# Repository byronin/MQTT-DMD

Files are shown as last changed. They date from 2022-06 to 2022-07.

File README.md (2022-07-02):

# MQTT-DMD for ESP8266

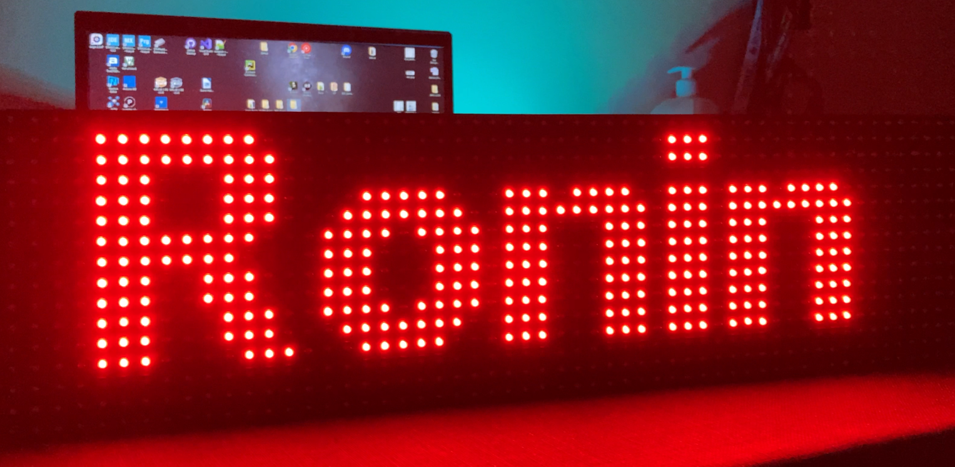
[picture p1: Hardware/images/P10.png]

## Contents
- PCB [Hardware](https://github.com/byronin/MQTT-DMD/tree/main/Hardware "Hardware") files prepared for controlling the P10 Display.
- [Arduino library](https://github.com/byronin/MQTT-DMD/tree/main/Lib%26Software "Arduino library")  for using P10 Display with Mqtt.

## Sponsor
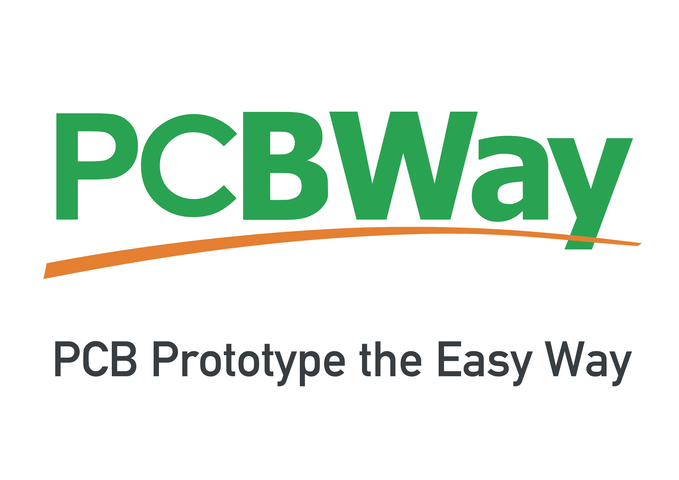
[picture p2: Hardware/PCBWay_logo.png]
(https://www.pcbway.com/project/shareproject/P10_Display_DMD_Text_Box_with_ESP8266_MQTT_P10_Display_Wi_Fi_Controller_4e9eb7f1.html)

#### Thanks to PCBWay for handling PCB production.
<a href="https://www.pcbway.com/project/shareproject/P10_Display_DMD_Text_Box_with_ESP8266_MQTT_P10_Display_Wi_Fi_Controller_4e9eb7f1.html">PCB from PCBWay</a>
## Hardware & BOM
PCBs
 This PCB Desing with Eagle PCB Desing with Eagle (https://www.autodesk.com/products/eagle/free-download "This PCB Desing with Eagle ") 
  ##### This PCB Desing with Eagle  
  
  ## Schematic
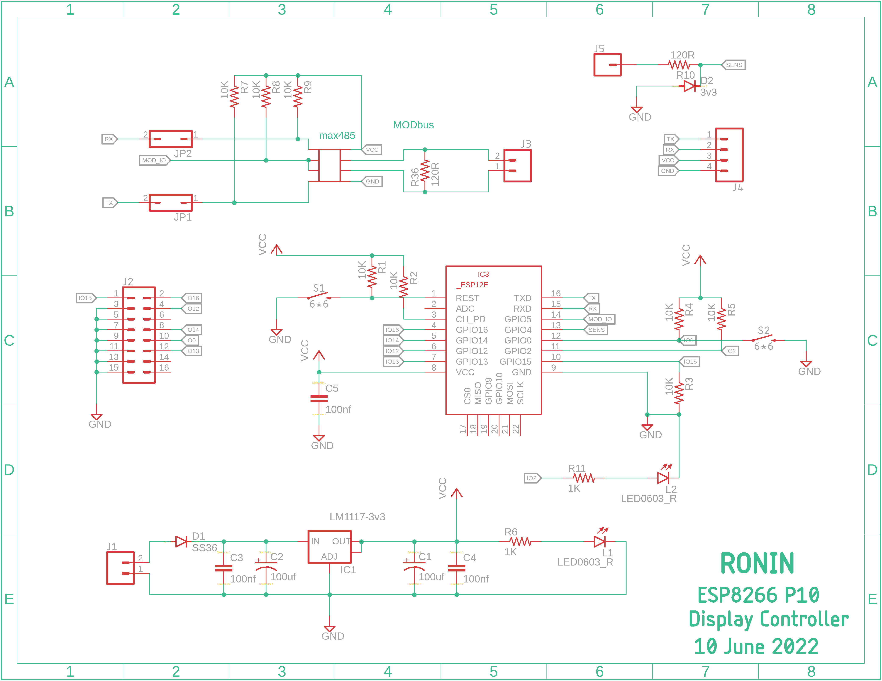
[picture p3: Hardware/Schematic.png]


| PCB Components  | Package |Piece || PCB Components  | Package |Piece |  
| --- | --- |--- |---| --- | --- |--- |
| ESP8266 Wi-Fi Module  | 12E | 1 pcs  || LM1117-3v3 | SOT-223  | 1 pcs |
| SS14/SS36 Diode  | DO-214AC | 1 pcs || 3v3 Zener Diode  | SOD80C | 1 pcs |
| MAX485-RS485 | SOP 8  | 1 pcs  || 100uf Cap | PANASONIC_D | 2 pcs |
| 100nf Cap mlcc | 0603  | 3 pcs || 10K Resistor  | 0603  | 8 pcs  |
| 1K Resistor | 0603  | 2 pcs || 120R Resistor  | 0603  | 2 pcs  |
| RED LED  | 0603  | 1 pcs || BLUE LED  | 0603  | 1 pcs  |
| Screw Terminal  | 3.5mm DIP  | 2 pcs  || Header 2x8 FML | 2.54-180  | 1 pcs  |
| Header 1x4 ML  | 2.54-90  | 1 pcs  || Header 1x2 ML  | 2.54-180  | 2 pcs  |
| JUMPER 1x2 | 2.54  | 2 pcs  |  

[You can look BOM.txt for details.](https://github.com/byronin/MQTT-DMD/blob/main/Hardware/BOM.txt "You can look BOM.txt")  

## Test 


#### Shopping List

| Product  | Link |
| --- | --- |
|P10 Display|[ Link](https://tr.aliexpress.com/item/1005003237909713.html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 " Link")|
| LM2596 |[Link](https://tr.aliexpress.com/item/33004374185.html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 "Link")|
| Power Jack |[Link](https://tr.aliexpress.com/item/32990462283.html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 "Link")  |
| 12V 3A Power Supply  | [Link](https://tr.aliexpress.com/item/32961533195.html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 "Link")  |

## Software & Library

- The project runs via the [Arduino IDE](https://www.arduino.cc/en/software "Arduino IDE"). If it is not installed, install it.
- Install [ESP8266](https://github.com/esp8266/Arduino "ESP8266") to Arduino.
- Install the [Pubsubclient Lib.](https://github.com/knolleary/pubsubclient "Pubsubclient Lib.") to Arduino.
- Install the [RoninDMD.zip](https://github.com/byronin/MQTT-DMD/blob/main/Lib%26Software/RoninDMD.zip "RoninDMD.zip") with library manager.
- You can connect with any MQTT client application. [MQTTool](https://apps.apple.com/us/app/mqttool/id1085976398 "MQTTool") application and [HiveMQ Public Broker](https://www.hivemq.com/public-mqtt-broker/ "HiveMQ Public Broker") were used in the testing phase of this project. Special thanks [@bjpetit](https://github.com/bjpetit "@bjpetit") .

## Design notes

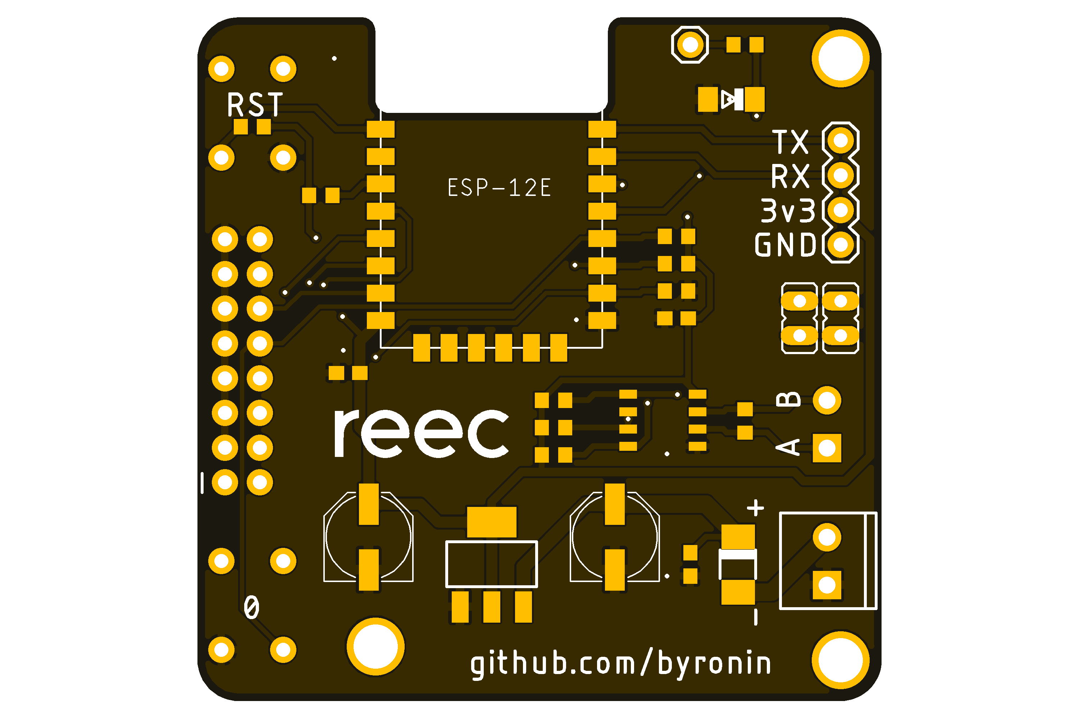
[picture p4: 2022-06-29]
Hardware/images/PCB1.png

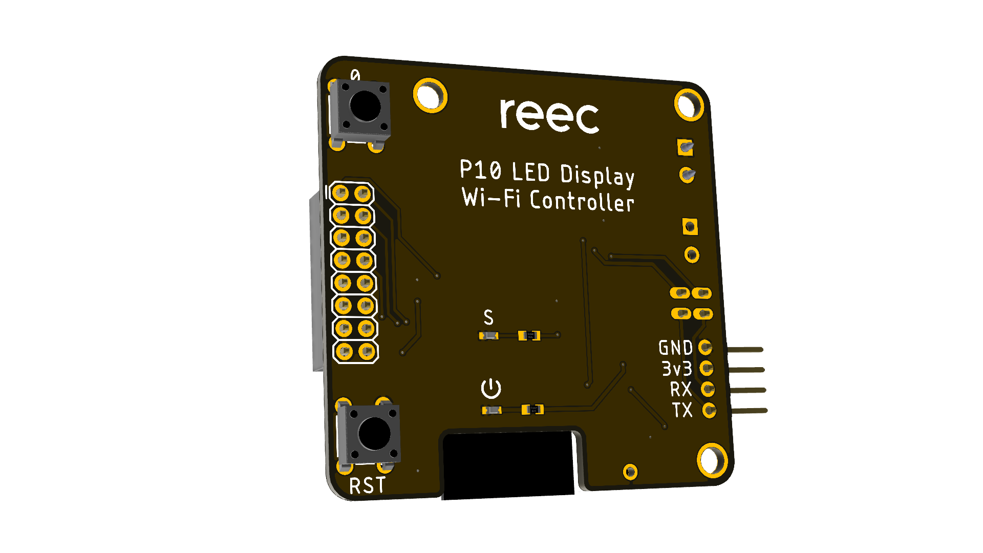
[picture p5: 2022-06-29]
Hardware/images/PCB_3D_2.png

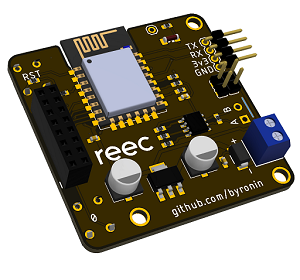
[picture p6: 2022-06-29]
Hardware/images/PCB_3D_1.png

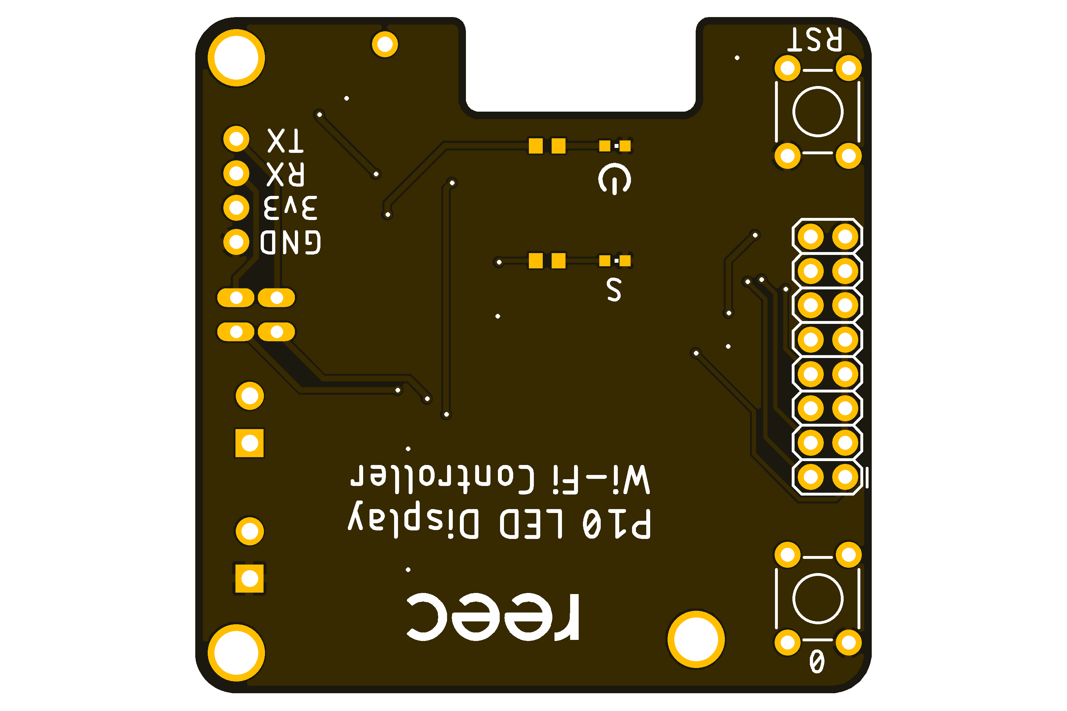
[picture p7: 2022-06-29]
Hardware/images/PCB2.png

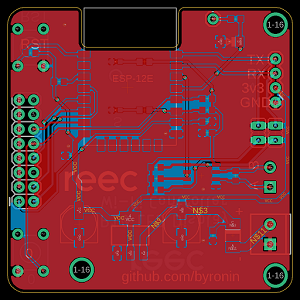
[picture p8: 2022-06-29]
Hardware/images/PCB_EAGLE.png

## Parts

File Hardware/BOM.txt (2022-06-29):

Partlist exported from C:/Users/Abdullah/Desktop/youtube/ESP8266_P10/Hardware/esp8266_p10/ESP8266_P10.sch at 12.06.2022 16:16

Part Value      Device                          Package                  Description                                                                                                      POPULARITY PROD_ID     SF_SKU   
C1   100uf      CAPACITOR_POLD                  PANASONIC_D                                                                                                                                                               
C2   100uf      CAPACITOR_POLD                  PANASONIC_D                                                                                                                                                               
C3   100nf      CAPACITOR_CER4                  C0603                                                                                                                                                                     
C4   100nf      CAPACITOR_CER4                  C0603                                                                                                                                                                     
C5   100nf      CAPACITOR_CER4                  C0603                                                                                                                                                                     
D1   SS36       DIODEAC2                        DO-214AC                                                                                                                                                                  
D2   3v3        DIODE80C                        SOD80C                                                                                                                                                                    
IC1  LM1117-3v3 V_REG_LM1117SOT223              SOT223                   Voltage Regulator LM1117                                                                                                                         
IC2  MAX485     SOP_8                           HSOP-8                                                                                                                                                                    
IC3             ESP8266-12EESP12E               ESP8266-ESP12E           ESP8266-12E Library for Eagle CAD                                                                                                                
J1              CONN_023.5MM                    SCREWTERMINAL-3.5MM-2    Multi connection point. Often used as Generic Header-pin footprint for 0.1 inch spaced/style header connections             CONN-08399           
J2              CONN_08X2                       2X8                      Multi connection point. Often used as Generic Header-pin footprint for 0.1 inch spaced/style header connections                                  
J3              CONN_023.5MM-NO_SILK            SCREWTERMINAL-3.5MM-2-NS Multi connection point. Often used as Generic Header-pin footprint for 0.1 inch spaced/style header connections             CONN-08399           
J4              CONN_04                         1X04                     Multi connection point. Often used as Generic Header-pin footprint for 0.1 inch spaced/style header connections             CONN-09696           
J5              CONN_01                         1X01                     Single connection point. Often used as Generic Header-pin footprint for 0.1 inch spaced/style header connections                                 
JP1             JP1Q                            JP1                      JUMPER                                                                                                           15                              
JP2             JP1Q                            JP1                      JUMPER                                                                                                           15                              
L1   LED0603_R  LED0603_R                       0603_LED_GREEN                                                                                                                                                            
L2   LED0603_R  LED0603_R                       0603_LED_GREEN                                                                                                                                                            
R1   10K        RESISTOR0603                    R0603                                                                                                                                                                     
R2   10K        RESISTOR0603                    R0603                                                                                                                                                                     
R3   10K        RESISTOR0603                    R0603                                                                                                                                                                     
R4   10K        RESISTOR0603                    R0603                                                                                                                                                                     
R5   10K        RESISTOR0603                    R0603                                                                                                                                                                     
R6   1K         RESISTOR0603                    R0603                                                                                                                                                                     
R7   10K        RESISTOR0603                    R0603                                                                                                                                                                     
R8   10K        RESISTOR0603                    R0603                                                                                                                                                                     
R9   10K        RESISTOR0603                    R0603                                                                                                                                                                     
R10  120R       RESISTOR0603                    R0603                                                                                                                                                                     
R11  1K         RESISTOR0603                    R0603                                                                                                                                                                     
R36  120R       RESISTOR0603                    R0603                                                                                                                                                                     
S1   6*6        MOMENTARY-SWITCH-SPST-PTH-6.0MM TACTILE_SWITCH_PTH_6.0MM Momentary Switch (Pushbutton) - SPST                                                                                         SWCH-08441 COM-00097
S2   6*6        MOMENTARY-SWITCH-SPST-PTH-6.0MM TACTILE_SWITCH_PTH_6.0MM Momentary Switch (Pushbutton) - SPST                                                                                         SWCH-08441 COM-00097

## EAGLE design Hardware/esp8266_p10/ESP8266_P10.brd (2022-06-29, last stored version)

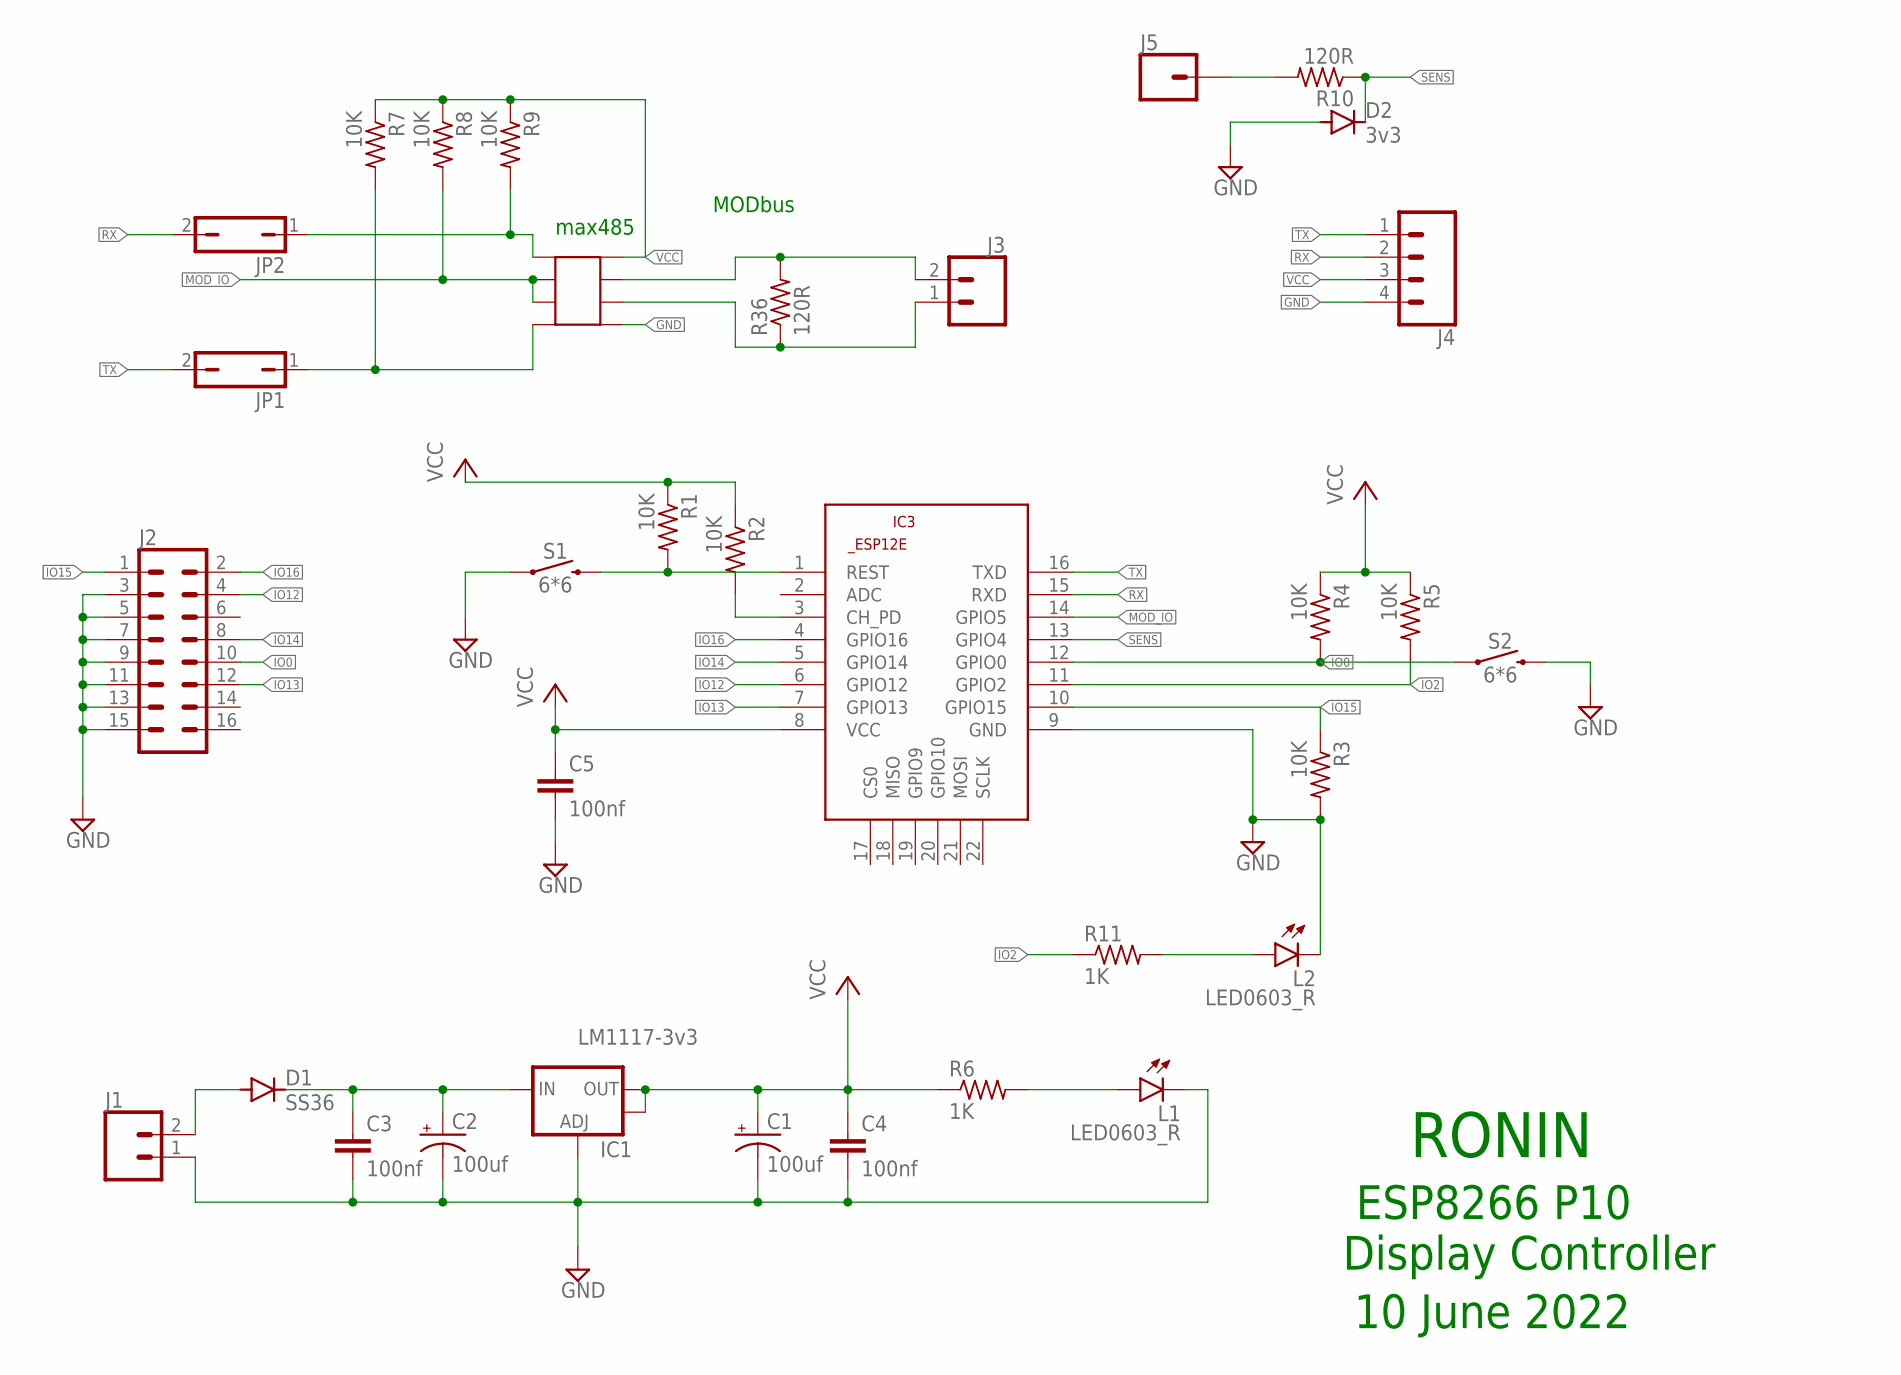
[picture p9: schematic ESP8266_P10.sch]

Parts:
C1, C2: 100uf; PANASONIC_D
C3, C4, C5: 100nf; C0603
D1: SS36; DO-214AC
D2: 3v3; SOD80C
IC1: LM1117-3v3; SOT223
IC2: MAX485; HSOP-8
IC3: ESP8266-12EESP12E; ESP8266-ESP12E
J1: CONN_023.5MM; SCREWTERMINAL-3.5MM-2
J2: CONN_08X2; 2X8
J3: CONN_023.5MM-NO_SILK; SCREWTERMINAL-3.5MM-2-NS
J4: CONN_04; 1X04
J5: CONN_01; 1X01
JP1, JP2: JP1Q; JP1
L1, L2: LED0603_R; 0603_LED_GREEN
R1, R2, R3, R4, R5, R7, R8, R9: 10K; R0603
R6, R11: 1K; R0603
R10, R36: 120R; R0603
S1, S2: 6*6; TACTILE_SWITCH_PTH_6.0MM

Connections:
CV: IC2.4, JP1.1, R7.2
FV: IC2.1, JP2.1, R9.2
GND: C1.-, C2.-, C3.2, C4.2, C5.2, D2.A, IC1.1 (ADJ), IC2.5, IC3.9 (GND), J1.1, J2.3, J2.5, J2.7, J2.9, J2.11, J2.13, J2.15, J4.4, L1.C, L2.C, R3.2, S1.1, S2.3 (2)
IO0: IC3.12 (GPIO0), J2.10, R4.2, S2.1
IO2: IC3.11 (GPIO2), R5.2, R11.1
IO12: IC3.6 (GPIO12), J2.4
IO13: IC3.7 (GPIO13), J2.12
IO14: IC3.5 (GPIO14), J2.8
IO15: IC3.10 (GPIO15), J2.1, R3.1
IO16: IC3.4 (GPIO16), J2.2
MOD_IO: IC2.2, IC2.3, IC3.14 (GPIO5), R8.2
unnamed: IC3.1 (REST), R1.2, S1.3 (2)
unnamed: IC3.3 (CH_PD), R2.2
unnamed: C2.+, C3.1, D1.C, IC1.3 (IN)
unnamed: L1.A, R6.2
unnamed: J5.1, R10.2
unnamed: L2.A, R11.2
unnamed: D1.A, J1.2
unnamed: IC2.7, J3.2, R36.2
unnamed: IC2.6, J3.1, R36.1
RX: IC3.15 (RXD), J4.2, JP2.2
SENS: D2.C, IC3.13 (GPIO4), R10.1
TX: IC3.16 (TXD), J4.1, JP1.2
VCC: C1.+, C4.1, C5.1, IC1.2 (OUT), IC1.4 (OUT), IC2.8, IC3.8 (VCC), J4.3, R1.1, R2.1, R4.1, R5.1, R6.1, R7.1, R8.1, R9.1

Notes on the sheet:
RONIN
ESP8266 P10 Display Controller
10 June 2022
MODbus
max485

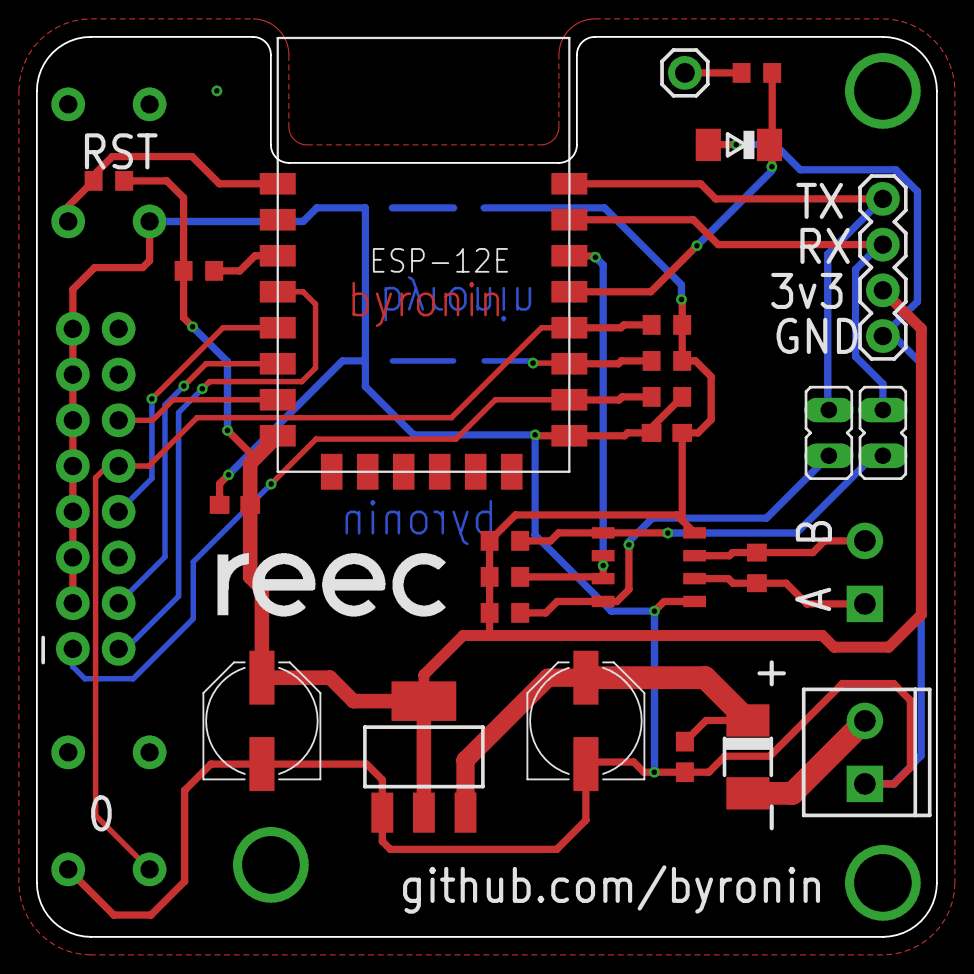
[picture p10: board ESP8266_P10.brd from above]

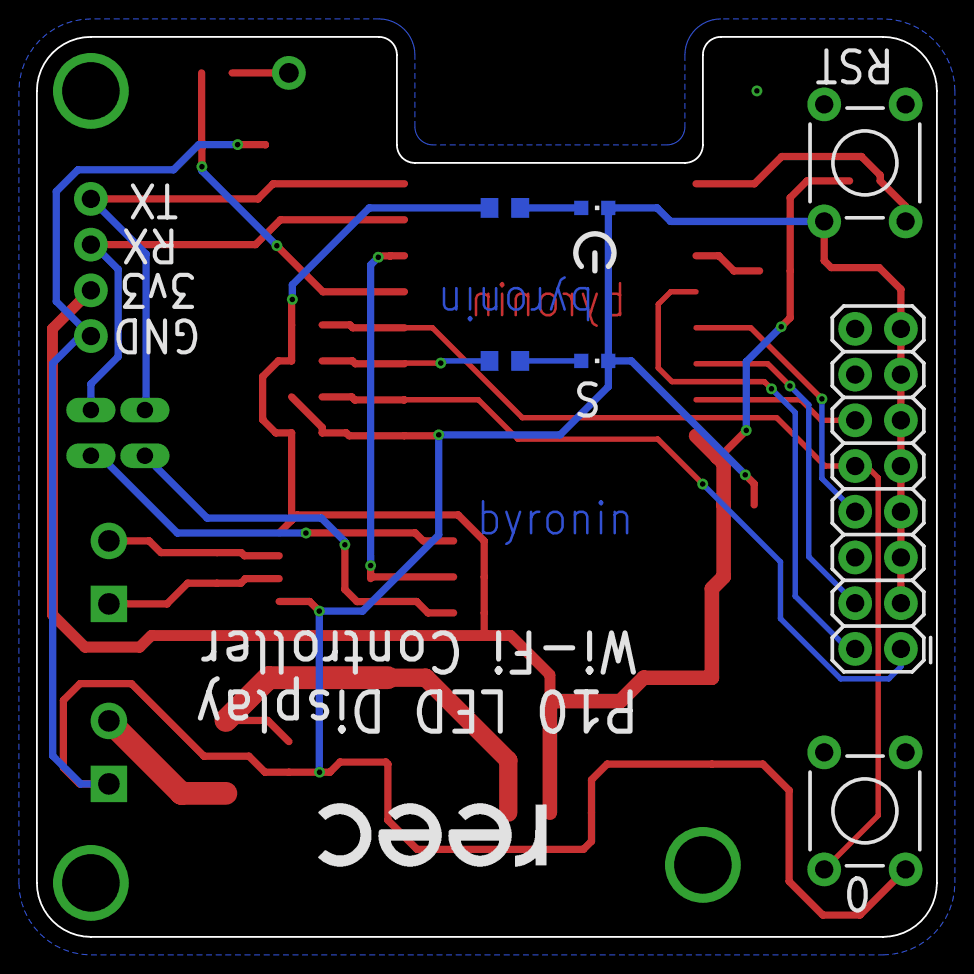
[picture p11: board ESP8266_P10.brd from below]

Board: 2 copper layers, 50.0 x 50.0 mm, 33 parts (7 on the bottom side), 24 nets.

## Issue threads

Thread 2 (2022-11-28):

Library Porting

akshaythoke9116, 2022-11-28:
Hello Ronin,

How are you? I want to convert your library to ESP32. If possible can you help me in the case.

byronin, 2023-01-03:
you can get: https://github.com/Qudor-Engineer/DMD32

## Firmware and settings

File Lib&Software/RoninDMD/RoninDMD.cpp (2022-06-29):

#include "RoninDMD.h"
#include "Arduino.h"
#include <string.h>
#include <stdlib.h>
#include "Bitmap.h"


#define DMD_PIN_PHASE_LSB       16   
#define DMD_PIN_PHASE_MSB       12  
#define DMD_PIN_LATCH           0    
#define DMD_PIN_OUTPUT_ENABLE   15   
#define DMD_PIN_SPI_MOSI        13    
#define DMD_PIN_SPI_SCK         14   


#define RoninDMD_NUM_COLUMNS      32    
#define RoninDMD_NUM_ROWS         16    

#define RoninDMD_REFRESH_US       100


RoninDMD::RoninDMD(int widthPanels, int heightPanels)
  : Bitmap(widthPanels * RoninDMD_NUM_COLUMNS, heightPanels * RoninDMD_NUM_ROWS)
  , _doubleBuffer(false)
  , phase(0)
  , fb0(0)
  , fb1(0)
  , displayfb(0)
  , lastRefresh(millis())
{ 
  fb0 = displayfb = fb; 

    pinMode(DMD_PIN_SPI_SCK, OUTPUT);
    pinMode(DMD_PIN_SPI_MOSI, OUTPUT);
    digitalWrite(DMD_PIN_SPI_SCK, LOW);
    digitalWrite(DMD_PIN_SPI_MOSI, LOW);
    pinMode(DMD_PIN_PHASE_LSB, OUTPUT);
    pinMode(DMD_PIN_PHASE_MSB, OUTPUT);
    pinMode(DMD_PIN_LATCH, OUTPUT);
    pinMode(DMD_PIN_OUTPUT_ENABLE, OUTPUT);
    digitalWrite(DMD_PIN_PHASE_LSB, LOW);
    digitalWrite(DMD_PIN_PHASE_MSB, LOW);
    digitalWrite(DMD_PIN_LATCH, LOW);
    digitalWrite(DMD_PIN_OUTPUT_ENABLE, LOW);
    digitalWrite(DMD_PIN_SPI_MOSI, HIGH);
}


RoninDMD::~RoninDMD()
{
  if (fb0)
    free(fb0);
  if (fb1)
    free(fb1);
  fb = 0; 
}


void RoninDMD::setDoubleBuffer(bool doubleBuffer)
{
    if (doubleBuffer != _doubleBuffer) {
        _doubleBuffer = doubleBuffer;
        if (doubleBuffer) {
           
            unsigned int size = _stride * _height;
            fb1 = (uint8_t *)malloc(size);

           
            if (fb1) {
                memset(fb1, 0xFF, size);
                cli();
                fb = fb1;
                displayfb = fb0;
                sei();
            } else {
                
                _doubleBuffer = false;
            }
        } else if (fb1) {
            
            cli();
            fb = fb0;
            displayfb = fb0;
            sei();

           
            free(fb1);
            fb1 = 0;
        }
    }
}


void RoninDMD::swapBuffers()
{
    if (_doubleBuffer) {
        cli();
        if (fb == fb0) {
            fb = fb1;
            displayfb = fb0;
        } else {
            fb = fb0;
            displayfb = fb1;
        }
        sei();
    }
}


void RoninDMD::swapBuffersAndCopy()
{
    swapBuffers();
    if (_doubleBuffer)
        memcpy((void *)fb, (void *)displayfb, _stride * _height);
}


extern "C" {
  #define USE_US_TIMER
  #include "user_interface.h"
  #include "osapi.h"
  #define os_timer_arm_us(a, b, c) ets_timer_arm_new(a, b, c, 0)
}

os_timer_t dispTimer;
bool tickOccured;

void timerCallback(void *pArg) {

  tickOccured = true;  

}

void dispinit(void) {
  
  system_timer_reinit();
  os_timer_setfn(&dispTimer, timerCallback, NULL);
  os_timer_arm_us(&dispTimer , RoninDMD_REFRESH_US, true);
      
}

void RoninDMD::loop()
{    
    if (tickOccured == true) {    
      tickOccured = false;
      refresh();
      system_timer_reinit();  
    }

}

static const uint8_t flipBits[256] PROGMEM = {
    0x00, 0x80, 0x40, 0xC0, 0x20, 0xA0, 0x60, 0xE0, 0x10, 0x90, 0x50, 0xD0,
    0x30, 0xB0, 0x70, 0xF0, 0x08, 0x88, 0x48, 0xC8, 0x28, 0xA8, 0x68, 0xE8,
    0x18, 0x98, 0x58, 0xD8, 0x38, 0xB8, 0x78, 0xF8, 0x04, 0x84, 0x44, 0xC4,
    0x24, 0xA4, 0x64, 0xE4, 0x14, 0x94, 0x54, 0xD4, 0x34, 0xB4, 0x74, 0xF4,
    0x0C, 0x8C, 0x4C, 0xCC, 0x2C, 0xAC, 0x6C, 0xEC, 0x1C, 0x9C, 0x5C, 0xDC,
    0x3C, 0xBC, 0x7C, 0xFC, 0x02, 0x82, 0x42, 0xC2, 0x22, 0xA2, 0x62, 0xE2,
    0x12, 0x92, 0x52, 0xD2, 0x32, 0xB2, 0x72, 0xF2, 0x0A, 0x8A, 0x4A, 0xCA,
    0x2A, 0xAA, 0x6A, 0xEA, 0x1A, 0x9A, 0x5A, 0xDA, 0x3A, 0xBA, 0x7A, 0xFA,
    0x06, 0x86, 0x46, 0xC6, 0x26, 0xA6, 0x66, 0xE6, 0x16, 0x96, 0x56, 0xD6,
    0x36, 0xB6, 0x76, 0xF6, 0x0E, 0x8E, 0x4E, 0xCE, 0x2E, 0xAE, 0x6E, 0xEE,
    0x1E, 0x9E, 0x5E, 0xDE, 0x3E, 0xBE, 0x7E, 0xFE, 0x01, 0x81, 0x41, 0xC1,
    0x21, 0xA1, 0x61, 0xE1, 0x11, 0x91, 0x51, 0xD1, 0x31, 0xB1, 0x71, 0xF1,
    0x09, 0x89, 0x49, 0xC9, 0x29, 0xA9, 0x69, 0xE9, 0x19, 0x99, 0x59, 0xD9,
    0x39, 0xB9, 0x79, 0xF9, 0x05, 0x85, 0x45, 0xC5, 0x25, 0xA5, 0x65, 0xE5,
    0x15, 0x95, 0x55, 0xD5, 0x35, 0xB5, 0x75, 0xF5, 0x0D, 0x8D, 0x4D, 0xCD,
    0x2D, 0xAD, 0x6D, 0xED, 0x1D, 0x9D, 0x5D, 0xDD, 0x3D, 0xBD, 0x7D, 0xFD,
    0x03, 0x83, 0x43, 0xC3, 0x23, 0xA3, 0x63, 0xE3, 0x13, 0x93, 0x53, 0xD3,
    0x33, 0xB3, 0x73, 0xF3, 0x0B, 0x8B, 0x4B, 0xCB, 0x2B, 0xAB, 0x6B, 0xEB,
    0x1B, 0x9B, 0x5B, 0xDB, 0x3B, 0xBB, 0x7B, 0xFB, 0x07, 0x87, 0x47, 0xC7,
    0x27, 0xA7, 0x67, 0xE7, 0x17, 0x97, 0x57, 0xD7, 0x37, 0xB7, 0x77, 0xF7,
    0x0F, 0x8F, 0x4F, 0xCF, 0x2F, 0xAF, 0x6F, 0xEF, 0x1F, 0x9F, 0x5F, 0xDF,
    0x3F, 0xBF, 0x7F, 0xFF
};

void RoninDMD::refresh(){

  int stride4 = _stride * 4;
  volatile uint8_t *data0;
  volatile uint8_t *data1;
  volatile uint8_t *data2;
  volatile uint8_t *data3;
  bool flipRow = ((_height & 0x10) == 0);
  for (byte y = 0; y < _height; y += 16) {
    if (!flipRow) {
      data0 = displayfb + _stride * (y + phase);
      data1 = data0 + stride4;
      data2 = data1 + stride4;
      data3 = data2 + stride4;
      for (int x = _stride; x > 0; --x) {
        SPI.write(*data3++);
        SPI.write(*data2++);
        SPI.write(*data1++);
        SPI.write(*data0++);
      }
      flipRow = true;
      
    } else {
        
      data0 = displayfb + _stride * (y + 16 - phase) - 1;
      data1 = data0 - stride4;
      data2 = data1 - stride4;
      data3 = data2 - stride4;
      for (int x = _stride; x > 0; --x) {
        SPI.transfer(pgm_read_byte(&(flipBits[*data3--])));
        SPI.transfer(pgm_read_byte(&(flipBits[*data2--])));
        SPI.transfer(pgm_read_byte(&(flipBits[*data1--])));
        SPI.transfer(pgm_read_byte(&(flipBits[*data0--])));
      }
      flipRow = false;
      
    }
  }

  pinMode(DMD_PIN_OUTPUT_ENABLE, INPUT);
  digitalWrite(DMD_PIN_LATCH, HIGH);
  digitalWrite(DMD_PIN_LATCH, LOW);
  digitalWrite(DMD_PIN_PHASE_LSB,bitRead(phase, LOW));
  digitalWrite(DMD_PIN_PHASE_MSB,bitRead(phase, HIGH));
  pinMode(DMD_PIN_OUTPUT_ENABLE, OUTPUT);
  analogWrite(DMD_PIN_OUTPUT_ENABLE, cr);
  phase = (phase + 1) & 0x03;

}

void RoninDMD::begin(){
  
  analogWriteFreq(16384);
  pinMode(SCK, SPECIAL);  
  pinMode(MOSI, SPECIAL);
  SPI1C = 0;
  SPI1U = SPIUMOSI | SPIUDUPLEX | SPIUSSE;
  SPI1U1 = (7 << SPILMOSI) | (7 << SPILMISO);
  SPI1C1 = 0;
  SPI1C &= ~(SPICWBO | SPICRBO);
  SPI1U &= ~(SPIUSME);SPI1P &= ~(1<<29);
  SPI.setFrequency(10000000); 
  byte jsh=0x11; 
  while(jsh--){if(jsh==DMD_PIN_PHASE_LSB||jsh==DMD_PIN_OUTPUT_ENABLE||jsh==DMD_PIN_PHASE_MSB||jsh==DMD_PIN_LATCH){
  digitalWrite(jsh, 0);pinMode(jsh,OUTPUT);}else{continue;}}
  tickOccured = false;
  dispinit();
  
}

void RoninDMD::setBrightness(uint16_t b){
  
  if(b==1){b=2;} 
  cr=b;
  
}


RoninDMD::Color RoninDMD::fromRGB(uint8_t r, uint8_t g, uint8_t b) 
{  
  if (r || g || b)
    return White;
  else
    return Black;    
}

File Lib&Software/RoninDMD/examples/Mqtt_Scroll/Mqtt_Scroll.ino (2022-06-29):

#include <ESP8266WiFi.h>
#include <PubSubClient.h>

#include <RoninDMD.h>                    // Include lib & font 
#include <fonts/Arial_Black_16.h>
#define FONT Arial_Black_16

#define WIDTH 1                          // Set width & height
#define HEIGHT 1
RoninDMD P10(WIDTH, HEIGHT);

const char *ssid         = "Your-SSID";  // Wi-Fi settings
const char *password     = "SSID-Password";
bool clnt_state = 0 ;

const char *mqtt_broker = "broker.hivemq.com"; // mqtt broker settings
const char *topic = "ronin_dsp_test"; // SET TOPIC !!!
const char *mqtt_username = "";
const char *mqtt_password = "";
const int mqtt_port = 1883;

String Message = "Hi Im Ronin";


WiFiClient espClient;
PubSubClient client(espClient);

void setup() {
  Serial.begin(115200);

  WiFi.begin(ssid, password);
  while (WiFi.status() != WL_CONNECTED) {

    delay(500);
    Serial.println("Connecting to WiFi..");


  }
  Serial.println("Connected to the WiFi network");
  //connecting to a mqtt broker
  client.setServer(mqtt_broker, mqtt_port);
  client.setCallback(callback);
  while (!client.connected()) {
    String client_id = "TEST-2152";
    client_id += String(WiFi.macAddress());
    Serial.printf("The client %s connects to the public mqtt broker\n", client_id.c_str());
    if (client.connect(client_id.c_str(), mqtt_username, mqtt_password)) {
      Serial.println("mqtt broker connected");
      clnt_state = 1;
    } else {
      clnt_state = 0 ;
      Serial.print("failed with state ");
      Serial.print(client.state());
      delay(2000);
    }
  }
  P10.begin();              // Begin the display & font
  P10.setFont(FONT);

  P10.setBrightness(20);    // Set the brightness

  P10.drawText(0 , 0, " :) "); // P10.drawText(position x , position y, String type text);
  client.subscribe(topic);
  client.publish("dsp_ronin", "dsp++");
}



void callback(char *topic, byte *payload, unsigned int length) {
  payload[length] = 0;
  Message  = String(( char *) payload);
  delay(100);
  Serial.println(Message);



}

void Scrolling_text(int text_height , int scroll_speed , String scroll_text ) {
  static uint32_t pM ;
  pM = millis();
  static uint32_t x = 0;
  scroll_text = scroll_text + " ";

  bool  scrl_while = 1 ;
  int dsp_width = P10.width();
  int txt_width = P10.textWidth(scroll_text);

  while (scrl_while == 1) {

    P10.loop();
    
    delay(1);
    if (millis() - pM > scroll_speed) {
      P10.setFont(FONT);
      P10.drawText(dsp_width - x, text_height, scroll_text);
      client.loop();

      x++;
      if (x >  txt_width + dsp_width) {

        x = 0 ;
        scrl_while = 0 ;

      }
      pM = millis();

    }


  }

}

void loop() {
  P10.loop();          // Run DMD loop
  client.loop();       // "Message" come from "callback" function
  
  Scrolling_text(0 , 50 , Message );  // Call the function to write scrolling text on screen.
                                      // like -> Scrolling_text( position y , scroll speed, String type text);
                                      // or for not scroll -> P10.drawText(position x , position y, String type text);

  delay(100);



  if (!client.connected()) {
    String client_id = "TEST-2152";
    client_id += String(WiFi.macAddress());
    Serial.printf("The client %s connects to the public mqtt broker\n", client_id.c_str());
    if (client.connect(client_id.c_str(), mqtt_username, mqtt_password)) {
      Serial.println("mqtt broker connected");
      clnt_state = 1;
      client.subscribe(topic);
    } else {
      clnt_state = 0 ;
      Serial.print("failed with state ");
      Serial.print(client.state());
      delay(2000);
    }
  }
}

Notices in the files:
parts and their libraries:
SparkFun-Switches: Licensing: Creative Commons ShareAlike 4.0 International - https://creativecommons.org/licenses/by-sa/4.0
